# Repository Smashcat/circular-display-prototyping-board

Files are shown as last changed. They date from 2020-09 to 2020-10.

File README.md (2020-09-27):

# 1.28" Circular display prototyping board

This is a small prototyping PCB designed for the East Rising ER-TFT1.28-2 240x240 TFT display module with 24 pin connector.

The small connector is too small to hand solder, so this must be reflowed, but as there is only one part on the PCB a heatgun or iron could be used for this.

All the pins have been broken out to separate header pins, so that the same board can be used for other displays using the same connector, in case the pinouts are different!

I've included all the tech docs I have here too.

3D render and CAD download [here](https://a360.co/3l4JOM3)

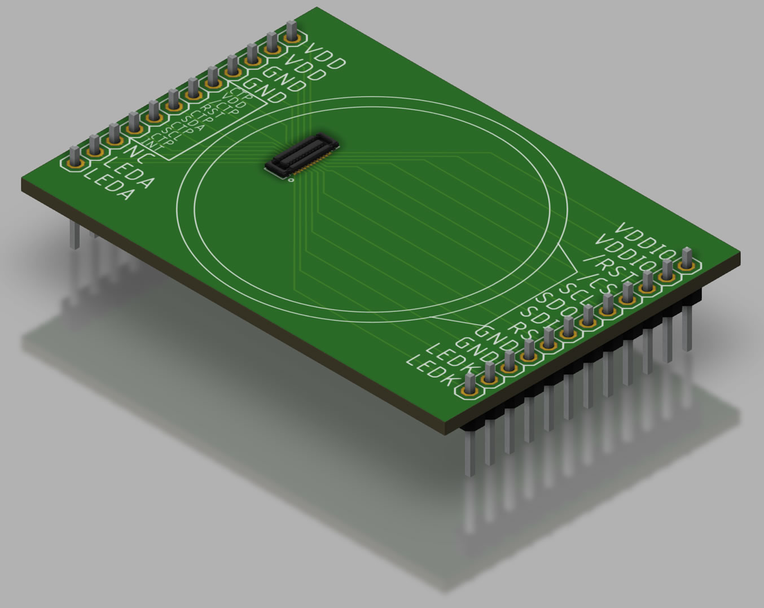
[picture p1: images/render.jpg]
Render


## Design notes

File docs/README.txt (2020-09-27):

Note the circular display can be found here:
https://www.buydisplay.com/240x240-round-ips-tft-lcd-display-1-28-inch-capactive-touch-circle-screen
Manufacturer: EastRising
Part #: ER-TFT1.28-2
Resolution: 240x240
Driver IC: GC9A01A
Diameter: 1.28"
Backlight current: 30mA (approx)
Backlight voltage: 3V

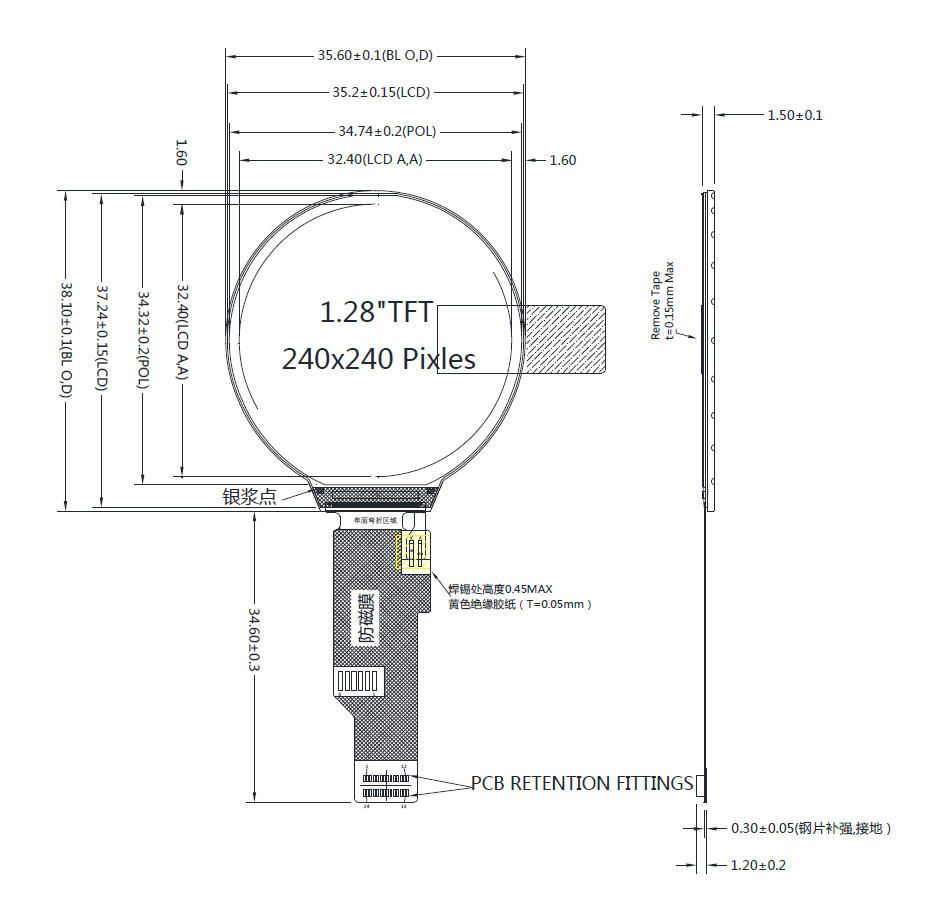
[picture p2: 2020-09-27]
docs/er-tft1.28-2_outline.jpg

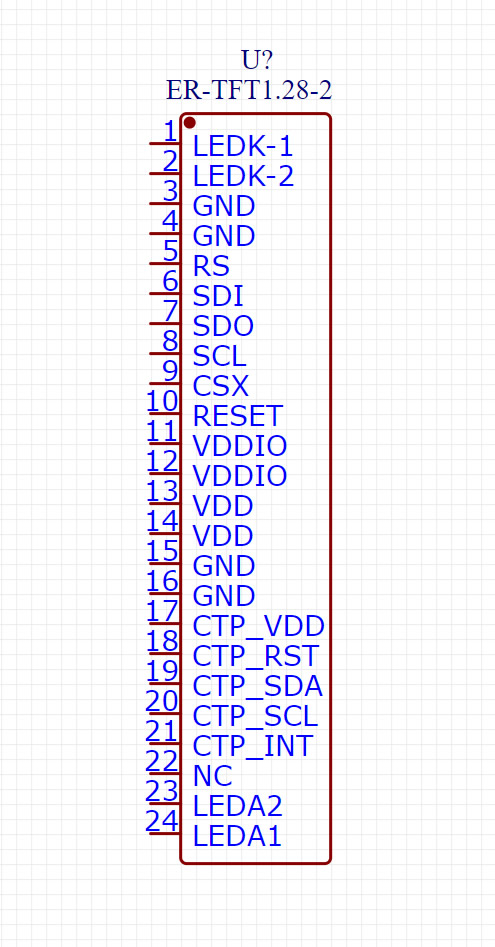
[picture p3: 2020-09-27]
docs/28-pin-0.4mm pitch connector.jpg

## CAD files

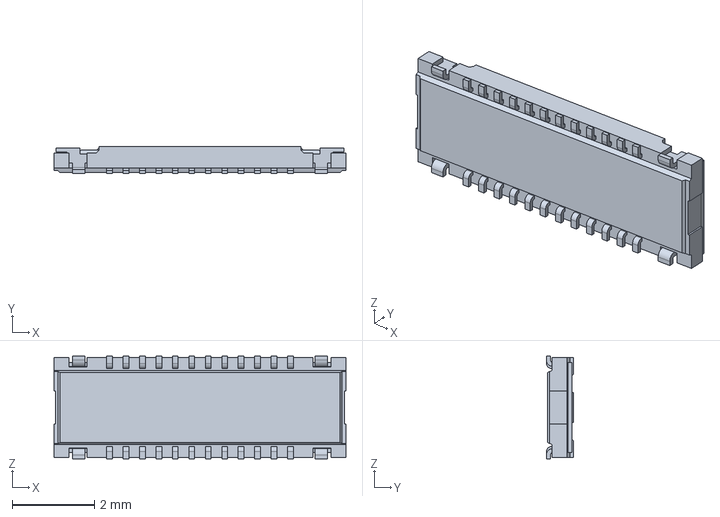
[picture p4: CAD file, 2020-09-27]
STEP models/5055502420.stp
7.10 x 0.66 x 2.50 mm

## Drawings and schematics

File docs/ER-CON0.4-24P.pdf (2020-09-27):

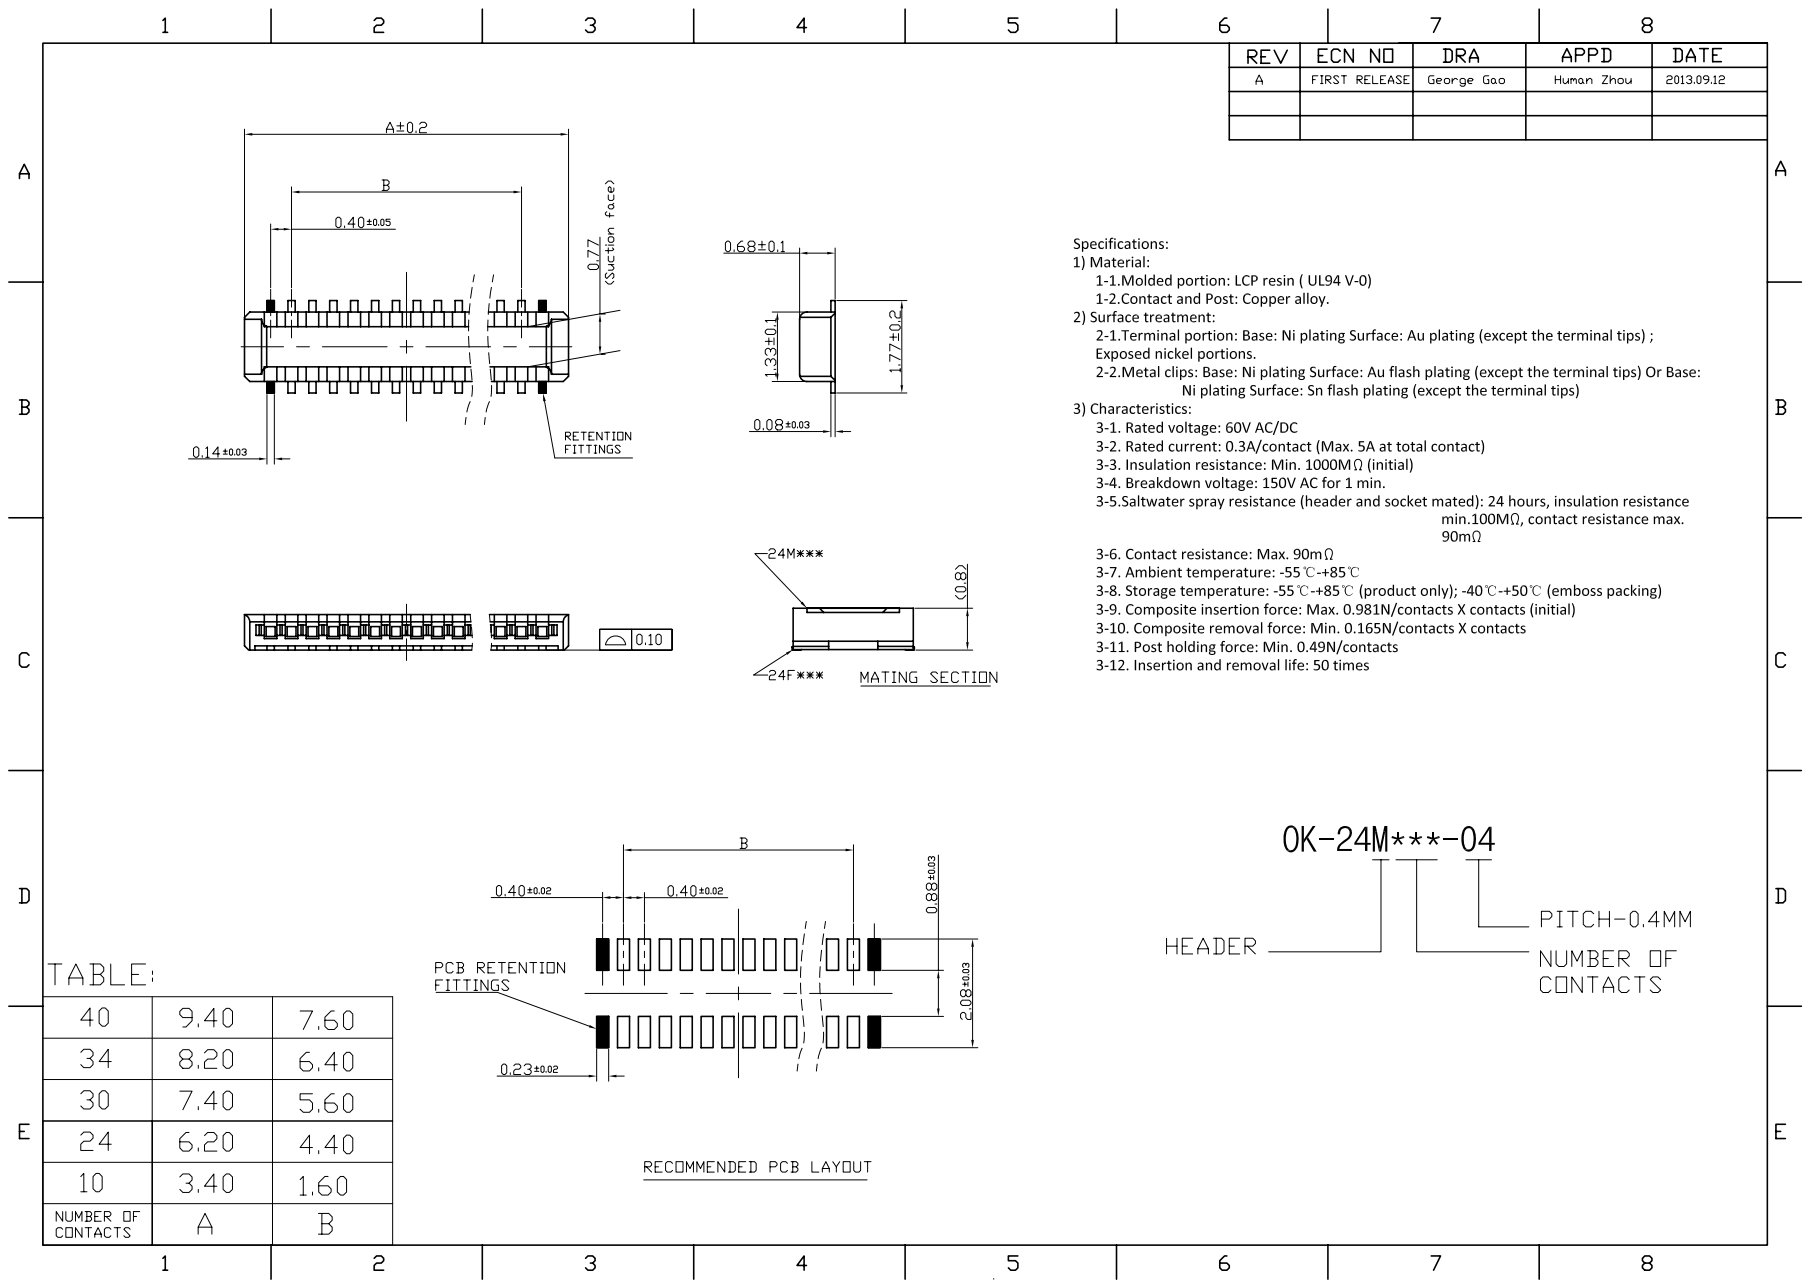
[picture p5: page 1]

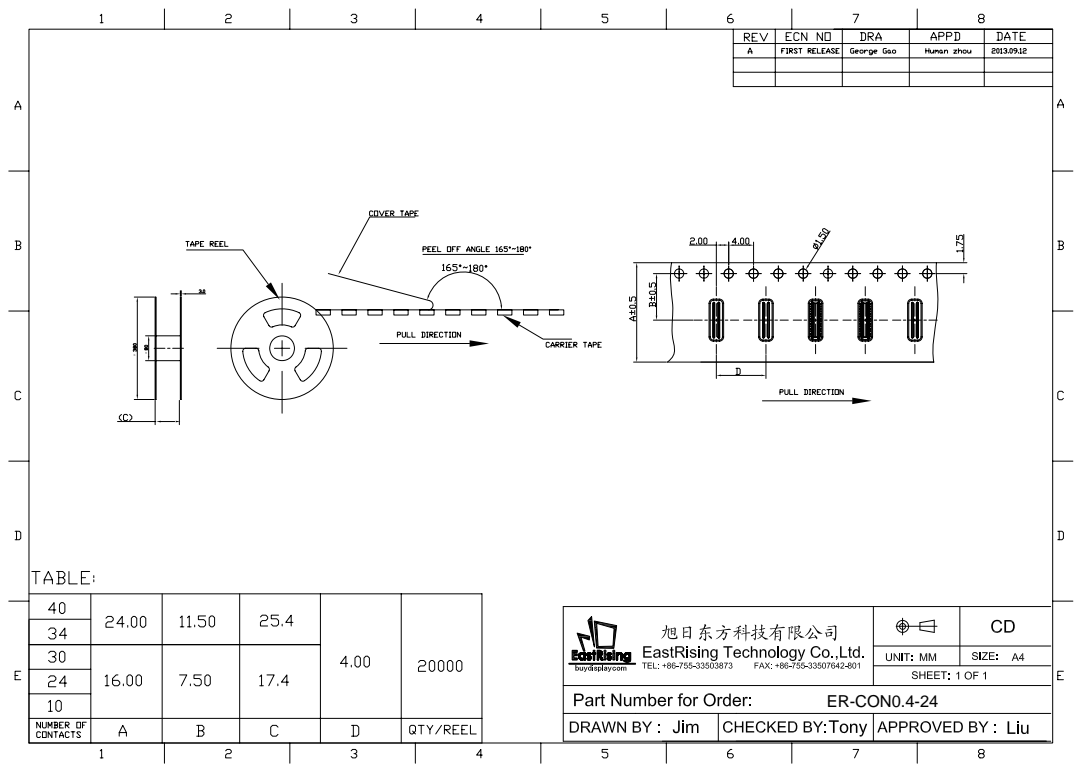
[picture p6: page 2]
ER-CON0.4-24

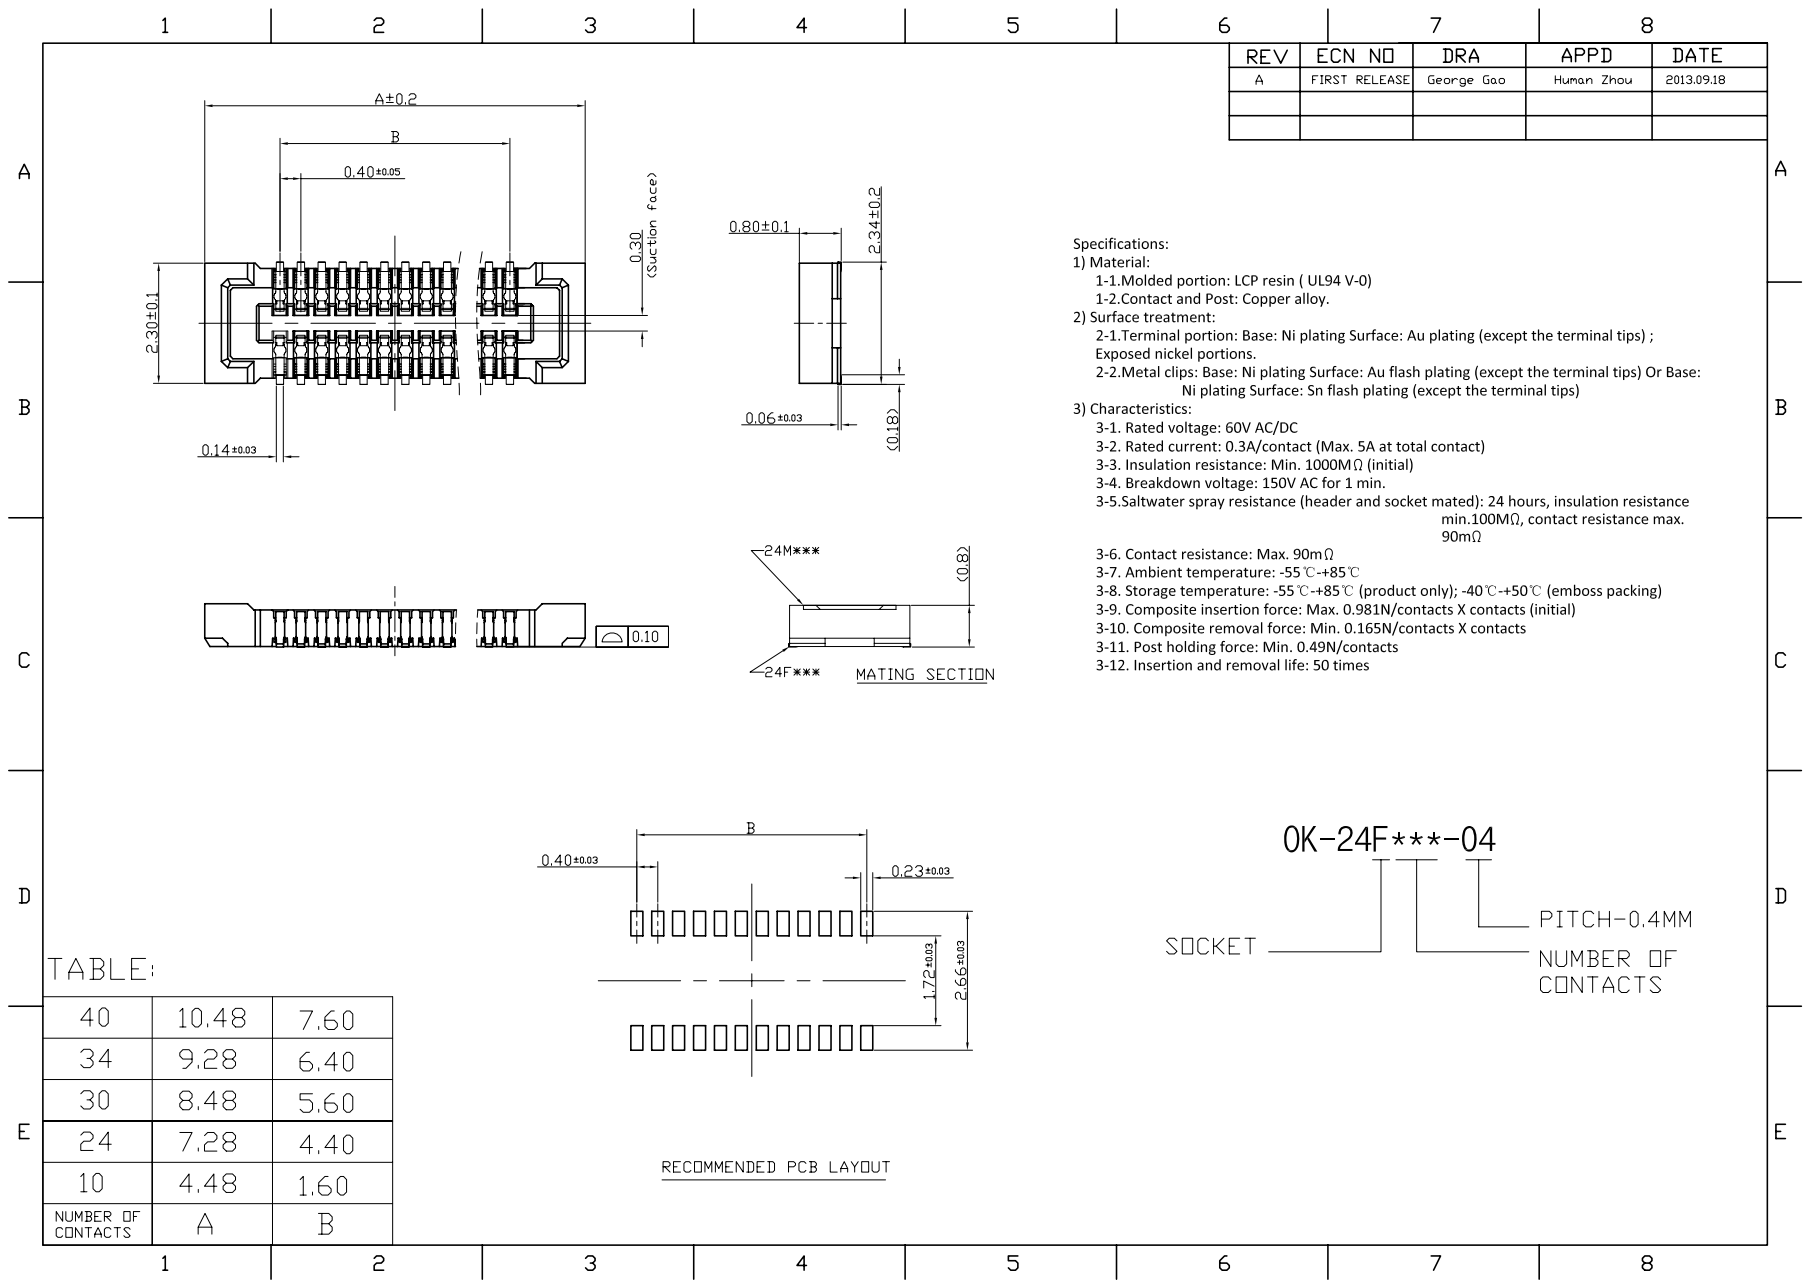
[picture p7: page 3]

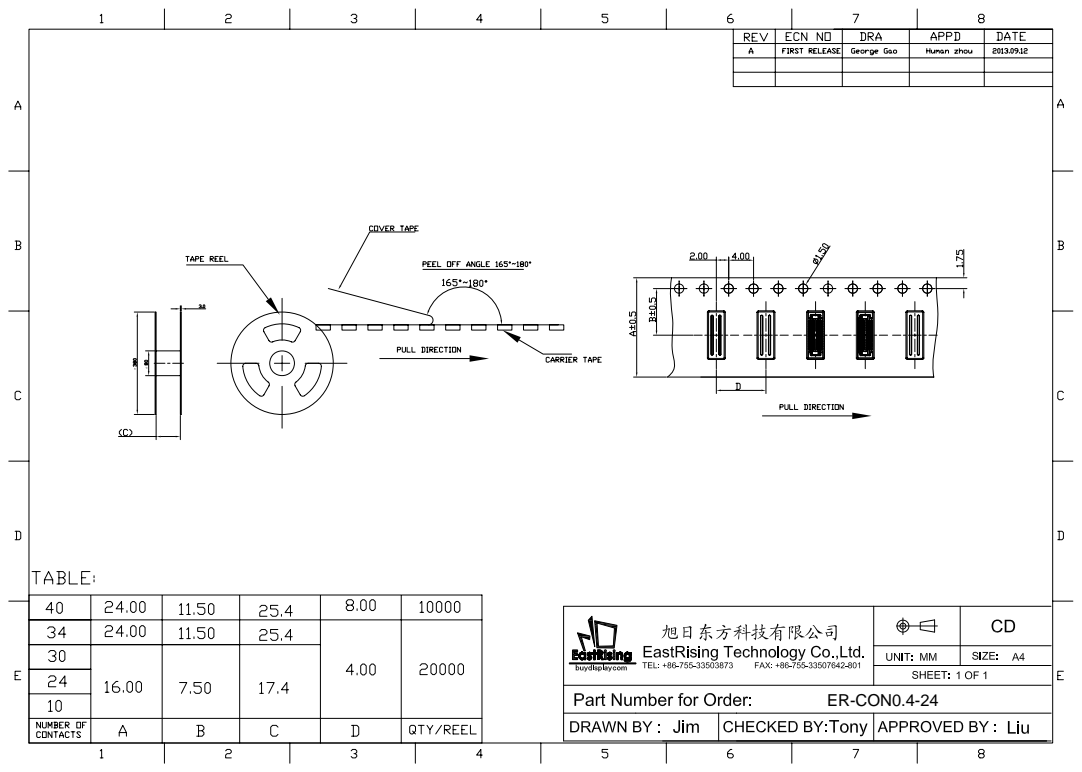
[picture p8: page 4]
ER-CON0.4-24

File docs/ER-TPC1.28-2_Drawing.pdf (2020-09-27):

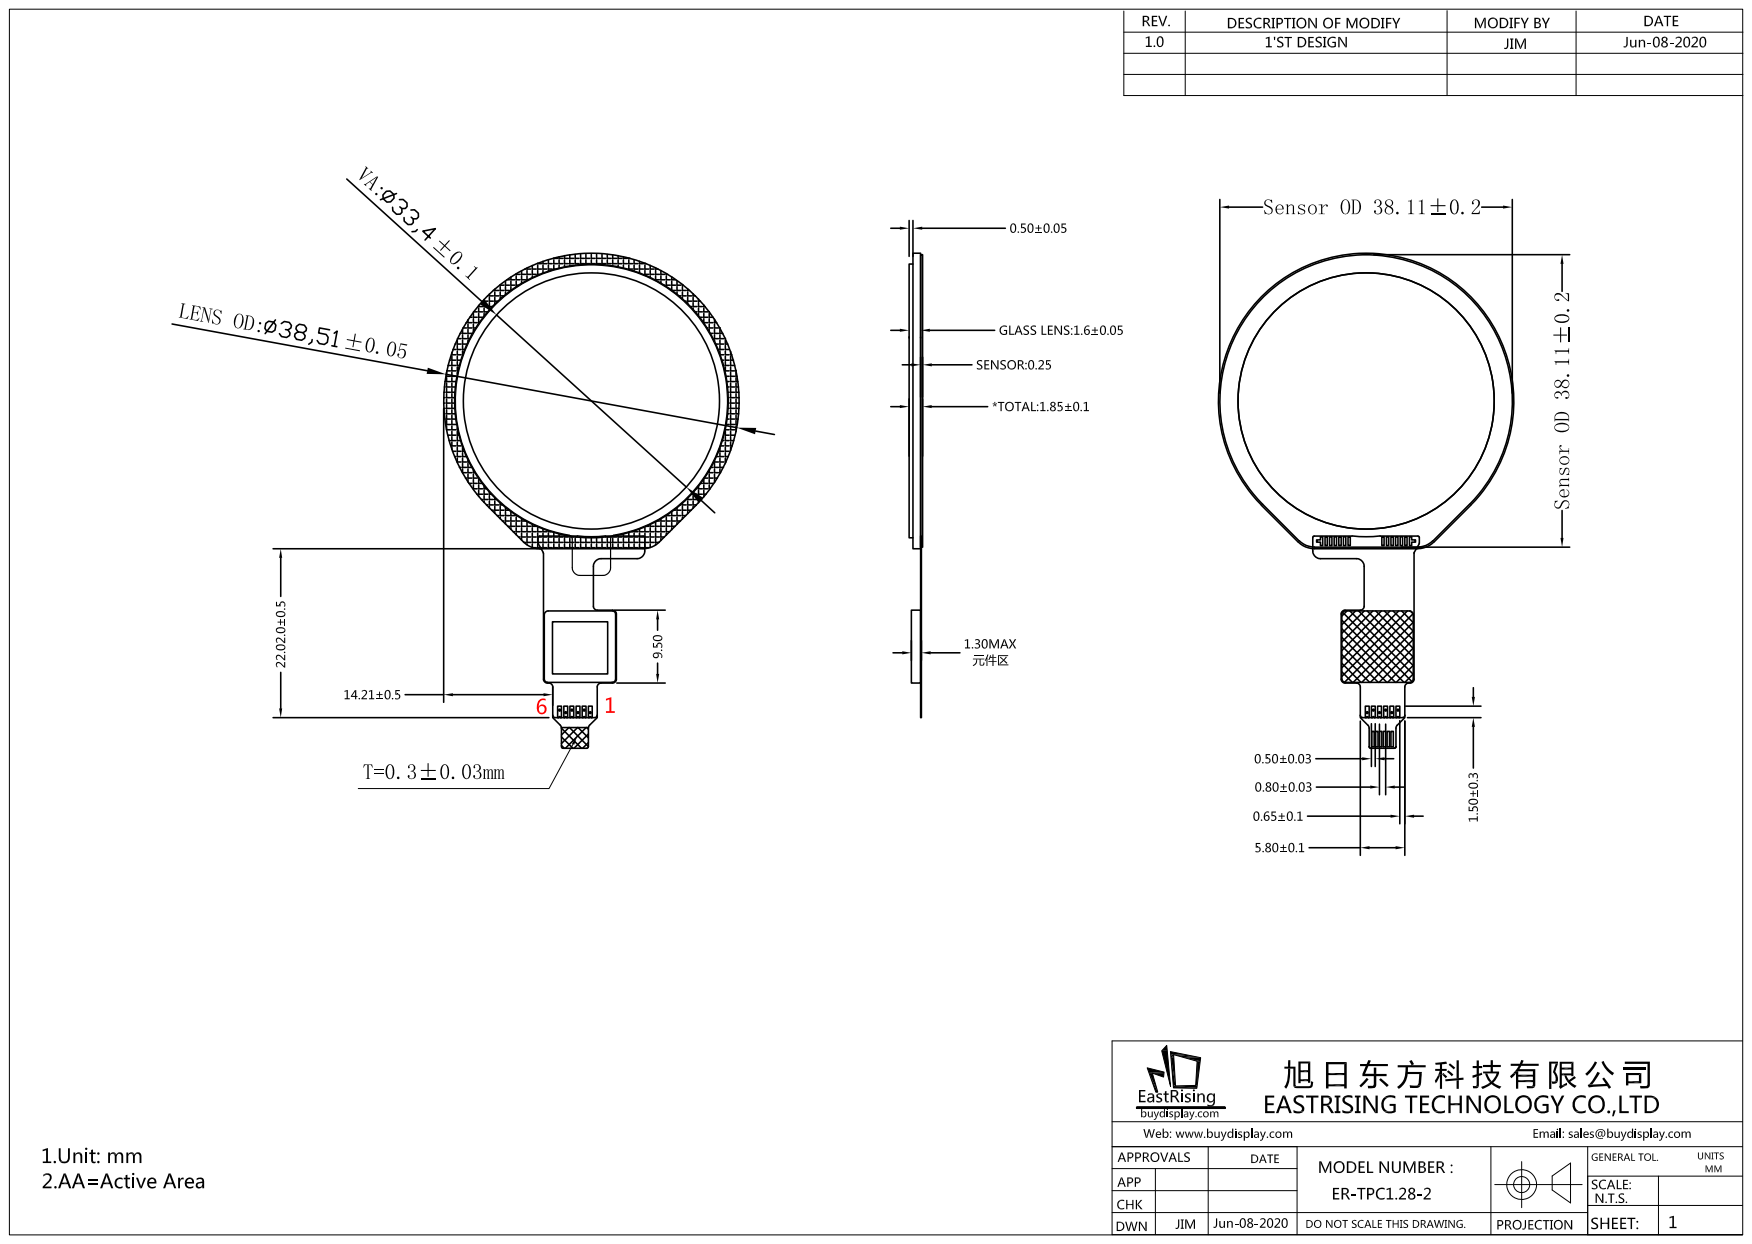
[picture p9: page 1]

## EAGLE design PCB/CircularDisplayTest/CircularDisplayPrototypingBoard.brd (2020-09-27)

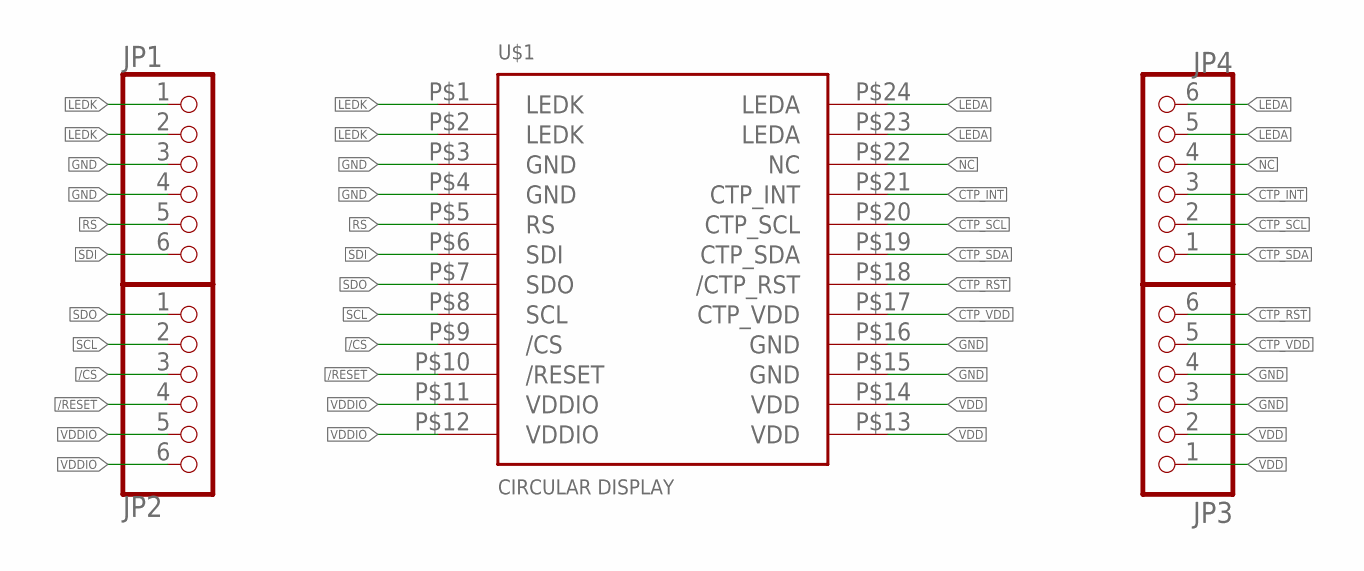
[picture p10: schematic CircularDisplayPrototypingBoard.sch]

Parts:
JP1, JP2, JP3, JP4: PINHD-1X6; 1X06
U$1: CIRCULAR-DISPLAY-1

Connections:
/CS: JP2.3, U$1.P$9 (/CS)
/RESET: JP2.4, U$1.P$10 (/RESET)
CTP_INT: JP4.3, U$1.P$21 (CTP_INT)
CTP_RST: JP3.6, U$1.P$18 (/CTP_RST)
CTP_SCL: JP4.2, U$1.P$20 (CTP_SCL)
CTP_SDA: JP4.1, U$1.P$19 (CTP_SDA)
CTP_VDD: JP3.5, U$1.P$17 (CTP_VDD)
GND: JP1.3, JP1.4, JP3.3, JP3.4, U$1.P$3 (GND), U$1.P$4 (GND), U$1.P$15 (GND), U$1.P$16 (GND)
LEDA: JP4.5, JP4.6, U$1.P$23 (LEDA), U$1.P$24 (LEDA)
LEDK: JP1.1, JP1.2, U$1.P$1 (LEDK), U$1.P$2 (LEDK)
NC: JP4.4, U$1.P$22 (NC)
RS: JP1.5, U$1.P$5 (RS)
SCL: JP2.2, U$1.P$8 (SCL)
SDI: JP1.6, U$1.P$6 (SDI)
SDO: JP2.1, U$1.P$7 (SDO)
VDD: JP3.1, JP3.2, U$1.P$13 (VDD), U$1.P$14 (VDD)
VDDIO: JP2.5, JP2.6, U$1.P$11 (VDDIO), U$1.P$12 (VDDIO)

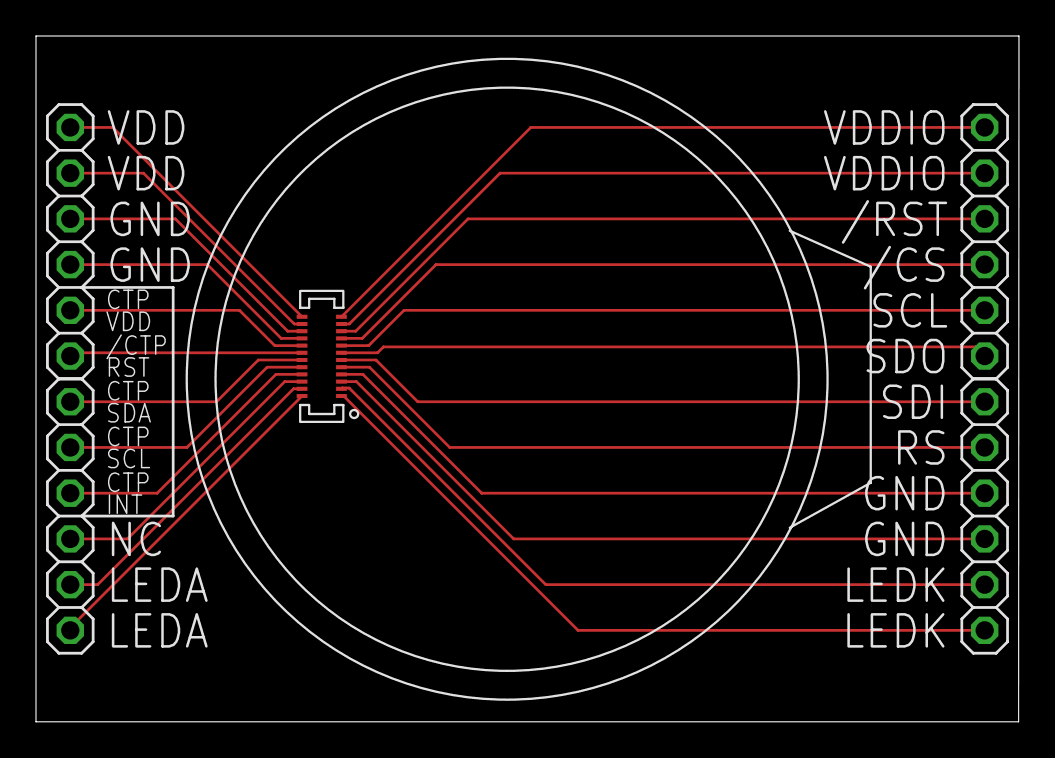
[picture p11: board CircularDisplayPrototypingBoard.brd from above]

Board: 2 copper layers, 54.6 x 38.1 mm, 5 parts (0 on the bottom side), 17 nets.

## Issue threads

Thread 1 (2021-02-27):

Touch pin connection

poky, 2021-02-27:
Hi, thanks for the awesome project!

Since the touch is using the I2C interface, do I use the default 21 & 22 pins for SCL & SDA? (I'm using ESP32)

Smashcat, 2021-02-27:
Thanks! Yep, 21 and 22 for i2c. You should also put pullups on those pins to ensure they work properly (usually 4k7 will work fine)

Smashcat, 2021-03-16:
No further actions.

Closed 2021-03-16.

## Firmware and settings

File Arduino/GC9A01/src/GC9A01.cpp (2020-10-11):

#include "Arduino.h"
#include <SPI.h>
#include "GC9A01.h"

/**
 * Constructor, requires a hardware SPI port using the default pins to allow 80Mhz mode on the ESP32
 */
GC9A01::GC9A01(SPIClass *s){
	spiRef=s;
	
	pinMode(TFT_MOSI,OUTPUT);
	pinMode(TFT_SCLK,OUTPUT);
	pinMode(TFT_CS,OUTPUT);
	pinMode(TFT_DC,OUTPUT);
	pinMode(TFT_RST,OUTPUT);
	pinMode(TFT_MISO,INPUT);

	CS_HIGH;
	delay(5);
	RST_LOW;
	delay(10);
	RST_HIGH;
	delay(120);  

	displayBuffer=new RenderBuffer(240,240);
	setTargetBuffer(displayBuffer);
//	buffer=new uint16_t[DISPLAY_WIDTH*DISPLAY_HEIGHT];
//	setRenderTarget(buffer,DISPLAY_WIDTH,DISPLAY_HEIGHT);
//	renderBuffer=buffer;

	CS_LOW;

	spiRef->beginTransaction(SPISettings(SPI_SPEED, MSBFIRST, SPI_MODE0));


	//************* Start Initial Sequence **********// 
	writeCmd(SET_INTER_REGISTER_ENABLE2);

	writeCmd(0xEB);
	writeCmdData(0x14); 

	writeCmd(SET_INTER_REGISTER_ENABLE1);       
	writeCmd(SET_INTER_REGISTER_ENABLE2); 

	// No idea what these do! No documentation for these registers in datasheet!
	writeCmd(0xEB);  
	writeCmdData(0x14); 

	writeCmd(0x84);      
	writeCmdData(0x40); 

	writeCmd(0x85);      
	writeCmdData(0xFF); 

	writeCmd(0x86);      
	writeCmdData(0xFF); 

	writeCmd(0x87);      
	writeCmdData(0xFF);

	writeCmd(0x88);      
	writeCmdData(0x0A);

	writeCmd(0x89);      
	writeCmdData(0x21); 

	writeCmd(0x8A);      
	writeCmdData(0x00); 

	writeCmd(0x8B);      
	writeCmdData(0x80); 

	writeCmd(0x8C);      
	writeCmdData(0x01); 

	writeCmd(0x8D);      
	writeCmdData(0x01); 

	writeCmd(0x8E);      
	writeCmdData(0xFF); 

	writeCmd(0x8F);      
	writeCmdData(0xFF); 


	writeCmd(SET_DISPLAY_FUNCTION_CONTROL);
	writeCmdData(0x00);       
	writeCmdData(0x00); 

	writeCmd(SET_MEMORY_ACCESS_CONTROL);

	if(USE_HORIZONTAL==0)
	writeCmdData(0x18);
	else if(USE_HORIZONTAL==1)
	writeCmdData(0x28);
	else if(USE_HORIZONTAL==2)
	writeCmdData(0x48);
	else 
	writeCmdData(0x88);

	writeCmd(SET_PIXEL_FORMAT);      
	writeCmdData(0x05); // 16 bits per pixel

	writeCmd(0x90);       // Undocumented
	writeCmdData(0x08);
	writeCmdData(0x08);
	writeCmdData(0x08);
	writeCmdData(0x08); 

	writeCmd(0xBD);       // Undocumented
	writeCmdData(0x06);

	writeCmd(0xBC);       // Undocumented
	writeCmdData(0x00); 

	writeCmd(0xFF);       // Undocumented
	writeCmdData(0x60);
	writeCmdData(0x01);
	writeCmdData(0x04);

	writeCmd(SET_POWER_CONTROL_2);      
	writeCmdData(0x13);
	writeCmd(SET_POWER_CONTROL_3);      
	writeCmdData(0x13);

	writeCmd(SET_POWER_CONTROL_4);      
	writeCmdData(0x22);

	writeCmd(0xBE);       // Undocumented
	writeCmdData(0x11); 

	writeCmd(0xE1);       // Undocumented
	writeCmdData(0x10);
	writeCmdData(0x0E);

	writeCmd(0xDF);       // Undocumented
	writeCmdData(0x21);
	writeCmdData(0x0c);
	writeCmdData(0x02);

	writeCmd(SET_GAMMA_1);   
	writeCmdData(0x45);
	writeCmdData(0x09);
	writeCmdData(0x08);
	writeCmdData(0x08);
	writeCmdData(0x26);
	writeCmdData(0x2A);

	writeCmd(SET_GAMMA_2);    
	writeCmdData(0x43);
	writeCmdData(0x70);
	writeCmdData(0x72);
	writeCmdData(0x36);
	writeCmdData(0x37);  
	writeCmdData(0x6F);


	writeCmd(SET_GAMMA_3);   
	writeCmdData(0x45);
	writeCmdData(0x09);
	writeCmdData(0x08);
	writeCmdData(0x08);
	writeCmdData(0x26);
	writeCmdData(0x2A);

	writeCmd(SET_GAMMA_4);   
	writeCmdData(0x43);
	writeCmdData(0x70);
	writeCmdData(0x72);
	writeCmdData(0x36);
	writeCmdData(0x37); 
	writeCmdData(0x6F);

	writeCmd(0xED);       // Undocumented
	writeCmdData(0x1B); 
	writeCmdData(0x0B); 

	writeCmd(0xAE);       // Undocumented
	writeCmdData(0x77);

	writeCmd(0xCD);       // Undocumented
	writeCmdData(0x63);   


	writeCmd(0x70);       // Undocumented
	writeCmdData(0x07);
	writeCmdData(0x07);
	writeCmdData(0x04);
	writeCmdData(0x0E); 
	writeCmdData(0x0F); 
	writeCmdData(0x09);
	writeCmdData(0x07);
	writeCmdData(0x08);
	writeCmdData(0x03);

	writeCmd(SET_FRAME_RATE);      
	writeCmdData(0x34);

	writeCmd(0x62);      // Undocumented
	writeCmdData(0x18);
	writeCmdData(0x0D);
	writeCmdData(0x71);
	writeCmdData(0xED);
	writeCmdData(0x70); 
	writeCmdData(0x70);
	writeCmdData(0x18);
	writeCmdData(0x0F);
	writeCmdData(0x71);
	writeCmdData(SET_INTER_REGISTER_ENABLE2);
	writeCmdData(0x70); 
	writeCmdData(0x70);

	writeCmd(0x63);      // Undocumented
	writeCmdData(0x18);
	writeCmdData(0x11);
	writeCmdData(0x71);
	writeCmdData(0xF1);
	writeCmdData(0x70); 
	writeCmdData(0x70);
	writeCmdData(0x18);
	writeCmdData(0x13);
	writeCmdData(0x71);
	writeCmdData(0xF3);
	writeCmdData(0x70); 
	writeCmdData(0x70);

	writeCmd(0x64);      // Undocumented
	writeCmdData(0x28);
	writeCmdData(0x29);
	writeCmdData(0xF1);	// 241 - could this be the width/height+1 ?
	writeCmdData(0x01);	// maybe first pixel?
	writeCmdData(0xF1); // As above
	writeCmdData(0x00); // As above
	writeCmdData(0x07);

	writeCmd(0x66);      // Undocumented
	writeCmdData(0x3C);
	writeCmdData(0x00);
	writeCmdData(0xCD);
	writeCmdData(0x67);
	writeCmdData(0x45);
	writeCmdData(0x45);
	writeCmdData(0x10);
	writeCmdData(0x00);
	writeCmdData(0x00);
	writeCmdData(0x00);

	writeCmd(0x67);      // Undocumented
	writeCmdData(0x00);
	writeCmdData(0x3C);
	writeCmdData(0x00);
	writeCmdData(0x00);
	writeCmdData(0x00);
	writeCmdData(0x01);
	writeCmdData(0x54);
	writeCmdData(0x10);
	writeCmdData(0x32);
	writeCmdData(0x98);

	writeCmd(0x74);      // Undocumented
	writeCmdData(0x10); 
	writeCmdData(0x85); 
	writeCmdData(0x80);
	writeCmdData(0x00); 
	writeCmdData(0x00); 
	writeCmdData(0x4E);
	writeCmdData(0x00);         

	writeCmd(0x98);      // Undocumented
	writeCmdData(0x3e);
	writeCmdData(0x07);

	writeCmd(SET_TEARING_EFFECT_LINE_ON);  
	writeCmd(0x21);

	writeCmd(SET_EXIT_SLEEP_MODE);

	spiRef->endTransaction();

	delay(120);
	spiRef->beginTransaction(SPISettings(SPI_SPEED, MSBFIRST, SPI_MODE0));
	writeCmd(SET_DISPLAY_ON);
	spiRef->endTransaction();
	delay(20);
}

GC9A01::~GC9A01(){
	delete[] displayBuffer;
}

void GC9A01::setDisplayEnable(boolean tf){
	if(tf){
		CS_LOW;
	}else{
		CS_HIGH;
	}
}

void GC9A01::setDisplayWindow(uint16_t x,uint16_t y,uint16_t x2,uint16_t y2){
	spiRef->beginTransaction(SPISettings(SPI_SPEED, MSBFIRST, SPI_MODE0));

	writeCmd(SET_HORIZONTAL_WRITE_WINDOW);   
	writeCmdData(x>>8);
	writeCmdData(x);
	writeCmdData(x2>>8);
	writeCmdData(x2);

	writeCmd(SET_VERTICAL_WRITE_WINDOW);   
	writeCmdData(y>>8);
	writeCmdData(y);
	writeCmdData(y2>>8);
	writeCmdData(y2);
	writeCmd(SET_START_MEMORY_WRITE);
}

void GC9A01::drawFrame(void){
	setDisplayWindow(0,0,DISPLAY_WIDTH-1,DISPLAY_HEIGHT-1);  // This also starts the transaction
	DC_HIGH;
	spiRef->writePixels(renderBuffer,DISPLAY_WIDTH*DISPLAY_HEIGHT*2);
	spiRef->endTransaction();
	++frames;
}

void GC9A01::clearBuffer(uint16_t bColor){
	// Abuse pointers a bit here to write 4 bytes at a time instead of 2 :-)
	uint32_t bColor32=(bColor<<16)+bColor;
	uint32_t *p=(uint32_t *)renderBuffer;
	uint16_t cnt=renderBufferSize/2;
	for(uint16_t n=0;n<cnt;n++){
		*p++=bColor32;
	}
}
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

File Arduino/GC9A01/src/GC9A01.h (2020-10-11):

/*
  GC9A01.h - Library for accessing 240x240 circular display
  Author: Scott Porter (scott@smashcat.org)
  Date: 26/09/2020
  using the GC9A01 display controller chip (with SPI configured as the default control method on COG)
  Released into the public domain.
*/
#ifndef GC9A01_h
#define GC9A01_h

#include "Arduino.h"
#include <SPI.h>

// Render types

#define RENDER_TYPE_OVERWRITE			1
#define RENDER_TYPE_XOR					2
#define RENDER_TYPE_ADDITIVE			4
#define RENDER_TYPE_SUBTRACTIVE			8
#define RENDER_TYPE_MERGE				16
#define RENDER_TYPE_ANTIALIAS			32

#define RENDER_TYPE_FLIP_VERTICAL		64
#define RENDER_TYPE_FLIP_HORIZONTAL		128

// Commands used to set up registers in the GC9A01 controller
#define SET_HORIZONTAL_WRITE_WINDOW   	0x2A
#define SET_VERTICAL_WRITE_WINDOW     	0x2B
#define SET_START_MEMORY_WRITE        	0x2C
#define SET_INTER_REGISTER_ENABLE1    	0xFE
#define SET_INTER_REGISTER_ENABLE2    	0xEF
#define SET_MEMORY_ACCESS_CONTROL     	0x36
#define SET_DISPLAY_ON                	0x29
#define SET_DISPLAY_FUNCTION_CONTROL  	0xB6
#define SET_PIXEL_FORMAT              	0x3A
#define SET_POWER_CONTROL_2           	0xC3
#define SET_POWER_CONTROL_3           	0xC4
#define SET_POWER_CONTROL_4           	0xC9

#define SET_GAMMA_1                   	0xF0
#define SET_GAMMA_2                   	0xF1
#define SET_GAMMA_3                   	0xF2
#define SET_GAMMA_4                   	0xF3

#define SET_FRAME_RATE                	0xE8
#define SET_TEARING_EFFECT_LINE_ON    	0x35
#define SET_EXIT_SLEEP_MODE           	0x11


// IO pin definitions
#define TFT_MISO 						19
#define TFT_MOSI 						23
#define TFT_SCLK 						18
#define TFT_CS    						5  // Chip select control pin
#define TFT_DC    						2  // Data Command control pin
#define TFT_RST   						13

// Display settings
#define DISPLAY_WIDTH					240			// Default width/height for the circular display 
#define DISPLAY_HEIGHT					240
#define USE_HORIZONTAL 					2  			//Set the display direction 0,1,2,3  four directions
#define SPI_SPEED                     	80000000	// Maximum speed possible for SPI bus on ESP32

// Convenience defines
#define CS_LOW  						digitalWrite(TFT_CS,LOW);
#define CS_HIGH  						digitalWrite(TFT_CS,HIGH);

#define DC_LOW  						digitalWrite(TFT_DC,LOW);
#define DC_HIGH  						digitalWrite(TFT_DC,HIGH);

#define RST_LOW  						digitalWrite(TFT_RST,LOW);
#define RST_HIGH  						digitalWrite(TFT_RST,HIGH);

#ifndef _swap_int16_t
#define swapInt16(a, b){int16_t t=a;a=b;b=t;}
#endif

typedef struct SpriteImg {
  uint8_t bpp;
  uint8_t paletteSize;
  uint8_t frameWidth;
  uint8_t frameHeight;
  uint16_t totalHeight;
  int16_t transparentColorIndex;
  const uint16_t *palette;
  const uint8_t *data;
} SpriteImg;

class GC9A01
{
  public:

	// Inner class, used to handle buffer data for rendering
  	class RenderBuffer
	{
		public:
		uint16_t *buffer;
		uint16_t width;
		uint16_t height;
		RenderBuffer(uint16_t w,uint16_t h);
		~RenderBuffer();
		void resize(uint16_t w,uint16_t h);
	};

	RenderBuffer *displayBuffer;				// Yeah, may seem weird, but I like having easy access to the display buffer...
	uint16_t *renderBuffer=NULL;				// For performance, this can be set to point to a target RenderBuffer's buffer array for subsequent drawing operations
	uint16_t renderBufferWidth=240;				// Width of current render target
	uint16_t renderBufferHeight=240;			// Height of current render target
	uint16_t renderBufferSize=(renderBufferWidth*renderBufferHeight);


	uint32_t frames=0;							// Just a frame counter - increments each time a frame is drawn
    GC9A01(SPIClass *s);						// Constructor - note we allocate 240x240x2 bytes of memory for internal display buffer
	~GC9A01();									// Destructor - we free the buffer here to release memory back to the sketch
    void setDisplayEnable(boolean tf);			// Sets the CS pin low to enable, or high to disable the SPI port on the display
	void setDisplayWindow(uint16_t x,uint16_t y,uint16_t x2,uint16_t y2);	// Specifies the section of the display we will push data into
	void drawFrame(void);						// Blits the display buffer into the display - this sets up the display window etc, so no need to do anything else
	void clearBuffer(uint16_t bColor);			// Empties the display buffer - sets all pixels to colour (black)
	void testEffect1(void);						// Just test code to create animation on display - can be useful to quickly check display is working ok
	void fillRect(int16_t x, int16_t y,int16_t x2, int16_t y2,uint16_t color);	// Draw a filled rectangle using specified drawing mode
	void fillTriangle(int16_t x0, int16_t y0, int16_t x1, int16_t y1, int16_t x2, int16_t y2, uint16_t color);	// Adapted from Adafruit library
	void drawHLine(int16_t x,int16_t y, uint16_t w,uint16_t color);
	void drawHLine(int16_t x,int16_t y, uint16_t w);
	void drawSpriteImg(const SpriteImg *s,int16_t x,int16_t y,uint16_t frame, uint16_t renderDirection=0);						// Draw a frame of a sprite image to the current RenderBuffer
	void drawSpriteImg(const SpriteImg *s,int16_t x,int16_t y,uint16_t w,uint16_t h,uint16_t frame, uint16_t renderDirection=0);	// Draw a frame of a sprite image, scaled to (w,h) pixels, to the current RenderBuffer
	void setRenderType(uint16_t r);				// Sets the renderType for subsequent drawing operations
	void setMergeAmount(uint16_t a);			// Set the strength of the source pixel being merged into the destination buffer when RENDER_TYPE_MERGE is used. Range is 0 to 16 Lower = weaker
	void setRenderPaletteIndex(uint16_t i);		// Change the render palette for a sprite
	void setTargetBuffer(RenderBuffer *r);		// Sets the RenderBuffer target for subsequent drawing operations (default is the display buffer)
	
	// TODO
	void copyBufferToBuffer(RenderBuffer dest,RenderBuffer src,int16_t destX,int16_t destY,uint16_t transparentColorIndex=9999);
	void scaleBufferToBuffer(RenderBuffer dest,RenderBuffer src,int16_t destX,int16_t destW,int16_t destH,uint16_t transparentColorIndex=9999);
	void copyBufferToDisplay(RenderBuffer src,int16_t destX,int16_t destY);
	
	inline uint16_t getColor16(uint8_t r,uint8_t g,uint8_t b){	// Returns the 16bit color value from the RGB values (0-255) ready to copy to the display render buffer
		return ((r>>3)<<11)+((g>>2)<<5)+(b>>3);
	}
			
  private:

	uint16_t renderPaletteIndex=0;				// Sprite images can have multiple palettes. The default is 0. If you have not added extra palettes, do not change this!
	uint16_t renderType=RENDER_TYPE_OVERWRITE;	// How pixels are written to the renderBuffer
	uint16_t mergeAmt=8;						// Opacity to use when drawing using the "merge" render type, range is 0-16

	const uint8_t bppMask[9]={0,1,3,0,15,0,0,0,255};
	uint16_t _cR,_cG,_cB,_color;
	
	SPIClass *spiRef; // Private reference to hardware SPI device

	void writeCmdData(unsigned char c);
	void writeCmd(unsigned char c);
};

#endif

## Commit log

2020-10-07 Added initial alpha version of Arduino library
    [sd.OBJ]
2020-10-08 Renamed firmware to Arduino, as it now contains only the Arduino lib and examples
